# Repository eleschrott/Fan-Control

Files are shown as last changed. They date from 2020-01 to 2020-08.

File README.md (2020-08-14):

# Fan-Control
### Controls by temperature the speed of a fan driven with PWM
***
This small project is intended for cooling situations where the focus is on maximum noise reduction. To achieve this goal, the temperature is measured with a sensor (LM35DT) and processed by a microcontroller. This µController generates a pulse width modulated signal with 32kHz for a fan. The duty cycle of this PWM is directly proportional to the measured temperature.

Only a few parts are needed. The software can be realized with the Arduino IDE or ohters. I use Visual Studio with the <br>[Visual Micro Plugin](https://www.visualmicro.com/), but also Atmel Studio or others should working well. Here we use an Atmel ATtiny85, but other types with at least one analog input and a PWM capable output are also suitable.
The program is small enough to work on narrow-breasted microcontrollers. Only an internal clock frequency of 8MHz is necessary to output the PWM signal at 32kHz. This frequency is necessary, because some fans tend to produce an unpleasant whistling sound at low frequencies. The controlled temperature range is between 20 and 150 degrees Celsius.

The example shown here, refers to an ATtiny85 from Atmel. For other types or manufacturers other fuses may be set. These can be found in the respective documentations of the µController.

[Circuit diagram and board layout](/KiCAD/Fancontrol) are also included, these files are created with [KiCad](https://kicad-pcb.org/).
***
For the hardware you need the following (fits on the attached board layout):
+ Atmel ATtiny85 or similar (SOIC-8)
+ Board mounted Temperature Sensor LM35DT (TO220) 
+ Darlington transistor TIP122 (TO220)
+ Diode 1N4007 (THT)
+ Resistors: 1k, 10k (SMD 0805)
+ Capacitors: 100n, 10µ (SMD 0603)
+ Connectors: 1x 2Pin, 1x 3Pin, 1x 4Pin (THT)
+ Pinheader 02x03 Pins (THT)
+ 12V DC fan

The project requires two DC voltages, 5V for the µController and 12V for the fan. The power consumption at 12V depends on the fan type. The control needs very little current (max.12mA). In order to cope with an increased power consumption of the fan, it is recommended to provide the transistor with a heat sink. At low current consumption, the transistor can be operated without.
The circuit board is designed in such a way that the transistor is soldered in reverse, with the front side lying on the board, so that the heat sink I have in stock, can be mounted as flat as possible.

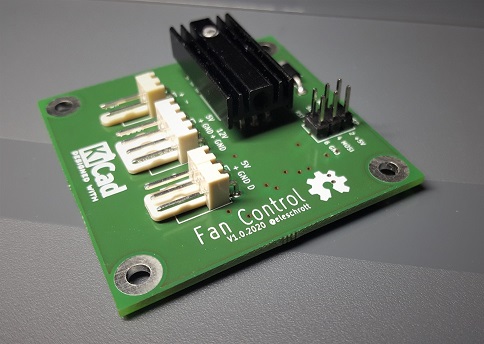
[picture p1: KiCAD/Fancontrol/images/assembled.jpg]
The parts I used for the circuit board were still available in my workshop. Of course, the used parts can vary in size and shape. It is only important that the microcontroller used, harmonizes with the software and that the peripherals can be controlled safely.
***
The circuit diagram is quite clear and does not require any great explanation. 
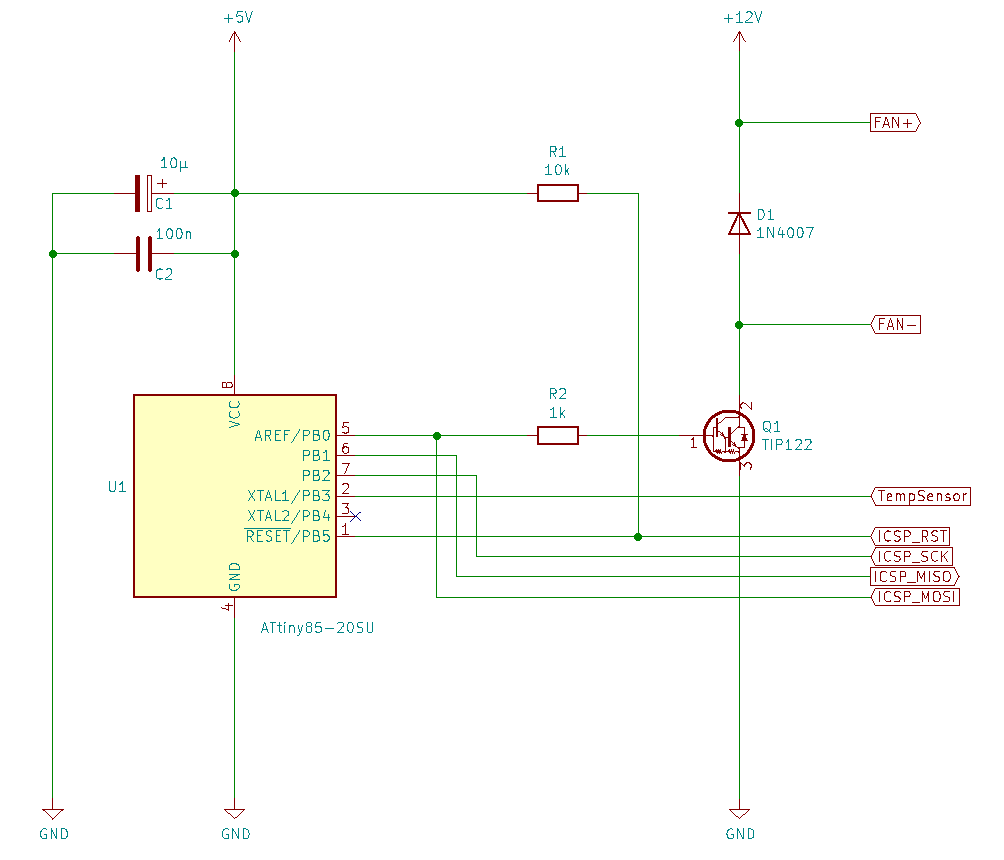
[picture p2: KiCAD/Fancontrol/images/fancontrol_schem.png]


***

In order to define the ranges for the control, the header file **Fancontrol.h** contains some constants, which can be adapted to the respective requirements.

```c
// Temperature values to define the ranges.
// We use no float variables, all temperatures gets calculated in 16Bit uint16_t!
// This means a value of 2350 corresponds to a temperature of 23.50 degrees Celsius
constexpr auto TEMP_MINHYS  = 2350; // Hysteresis for minimum temp to switch off the running fan
constexpr auto TEMP_MIN     = 2500; // Minimum Temp to switch on the fan
constexpr auto TEMP_NORMHYS = 2850; // Hysteresis for temp to switch normal range off
constexpr auto TEMP_NORM    = 3000; // Start of normal range
constexpr auto TEMP_MID     = 5000; // Temp to go to high range
constexpr auto TEMP_MAX     = 7500; // Max temperature
constexpr auto TEMP_OFFSET  =   15; // Minimum integer offset, from which a temperature control
                                    // becomes effective, default is 15 -> 0.15 degree.
```

There are also constants for the adaptation of the used fan. Not every fan runs with the same PWM values.
```c
// Fan responsible parameter to run the fan in smooth and low noise as possible
// Adjust this values to your fan model!
constexpr auto FAN_OFF      =   0; // PWM 0 -> Fan off!
constexpr auto FAN_LOWLOW   =  63; // Lowest PWM to run the fan save on minimum noise
constexpr auto FAN_LOW      =  75; // Minimum for controlled "normal" run
constexpr auto FAN_MID      = 150; // Maximum for controlled normal run and minimum for high speed run
constexpr auto FAN_HIGH     = 255; // Maximum for controlled high speed
constexpr auto FAN_OFFSET   =   2; // Minimum integer offset, from which a PWM regulation
                                   // becomes effective, default is 2 -> ~ 0.8%. 
```
***
To get this project working with the Arduino IDE, you need to install a board file to give the IDE knowledge about the ATtiny. Here you can find it: https://github.com/SpenceKonde/ATTinyCore.
To operate the µController with 8MHz some fuses must be set. For the Arduino IDE, this is described in the file [How2SetCPUFuses.txt](/Arduino/FanControl/How2SetCPUFuses.txt).

On the web site [Engbedded](http://www.engbedded.com/fusecalc) you can find a "AVR Fuse Calculator". Here you can verify the Low, High and Extended fuses.
```
avrdude: safemode: lfuse reads as E2
avrdude: safemode: hfuse reads as D7
avrdude: safemode: efuse reads as FF
```
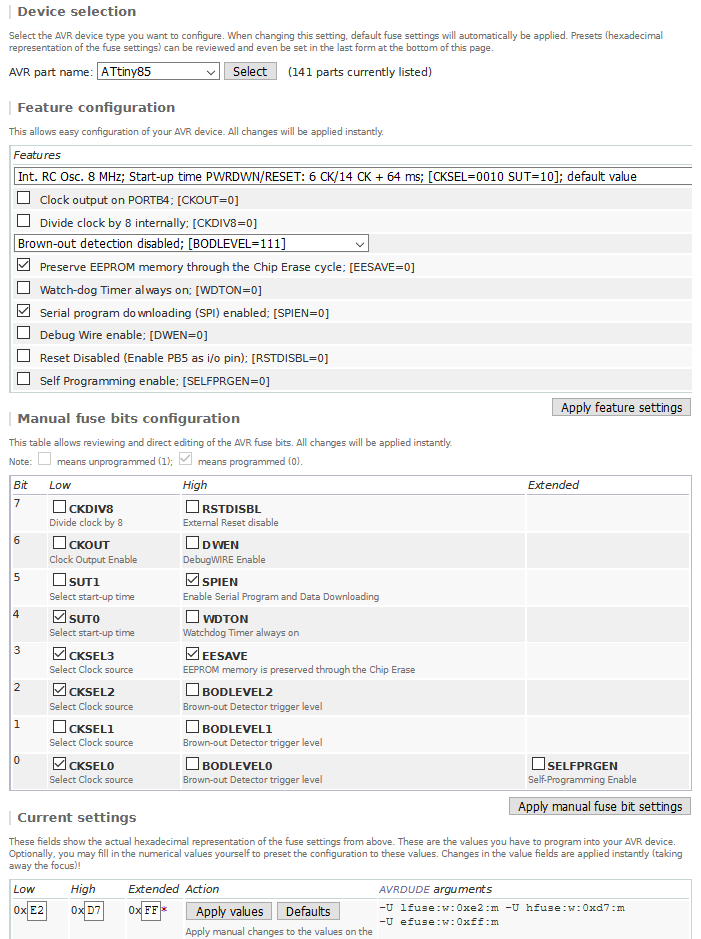
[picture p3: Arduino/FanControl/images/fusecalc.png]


***
ISP is used to program the microcontroller. It is also possible to flash the µcontroller before soldering and omit the pin headers for ISP. For adjustments to the program it is recommended to mount the 6pin header.
***

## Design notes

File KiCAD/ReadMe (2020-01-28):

Here you can find the KiCAD files, including schematic and pcb layout

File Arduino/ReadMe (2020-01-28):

Here you can find the raw Arduino version

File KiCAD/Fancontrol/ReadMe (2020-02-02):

Files for KiCad 5.1.5

It is not necessary to have a two-sided circuit board. If you want to make the circuit board yourself, one layer is perfectly sufficient.
The layout included here is single sided, the top side consists only of a groundplane.

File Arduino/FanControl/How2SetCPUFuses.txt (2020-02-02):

####################################################
# How to set the ATtiny fuses with the Arduino IDE #
####################################################

For this project you need to install a board file to give the IDE knowledge about the ATtiny.
Here you can find it: https://github.com/SpenceKonde/ATTinyCore

You can program the ATtiny by ISP. I use here an Atmel ICE in ISP mode, but also an Arduino Uno is handy to program this µController.

To set the CPU frequency to 8MHz with the Arduino IDE, you need to start to burn a bootloader.
This doesn't burn a bootloader in reality, but sets the needed fuses on the Tiny.

Set the fuses:
----------------------------------------------------
Start the Arduino IDE.

Use the following settings (e.g. for a ATtiny85):

1. Select board					: ATtiny25/45/85
2. Select chip					: ATtiny85
3. Select clock					: 8 MHz internal
4. B.O.D. level					: B.O.D. disabled
5. Save EEPROM					: EEPROM retained
6. Timer 1 clock				: CPU
7. LTO						: enabled
8. millis()/micros()    			: disabled

Execute the menu item Tools / Burn Bootloader.
----------------------------------------------------

This changes the fuses so the processor runs at 8 MHz using the internal oscillator.
It's also a handy way of "erasing" the processor when switching between projects.

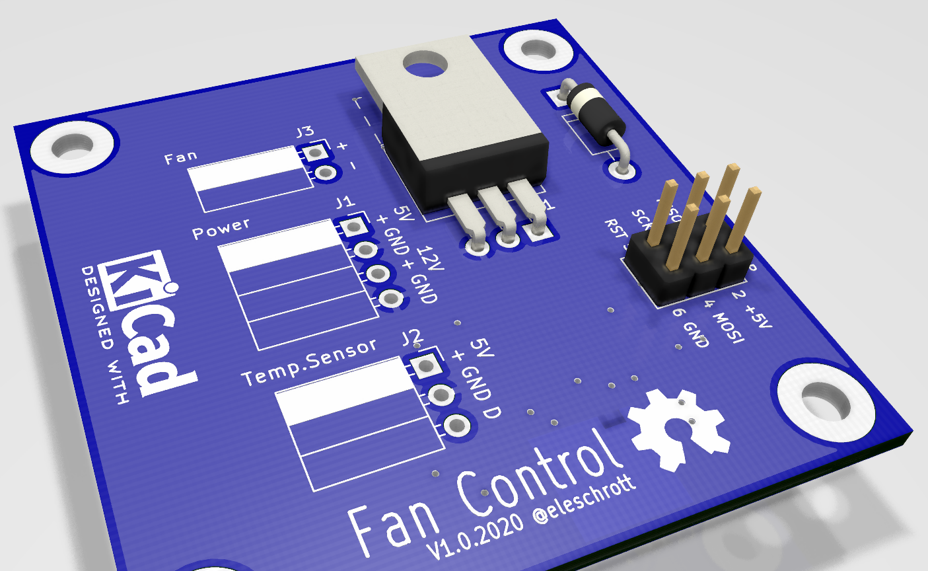
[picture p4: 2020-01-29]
KiCAD/Fancontrol/images/pcb_top.png

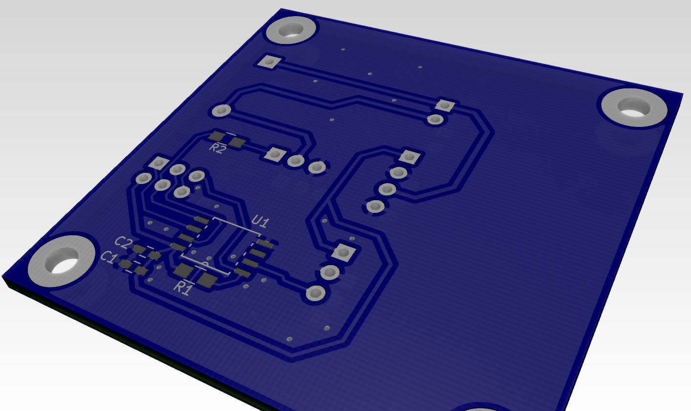
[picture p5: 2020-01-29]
KiCAD/Fancontrol/images/pcb_back_raw.png

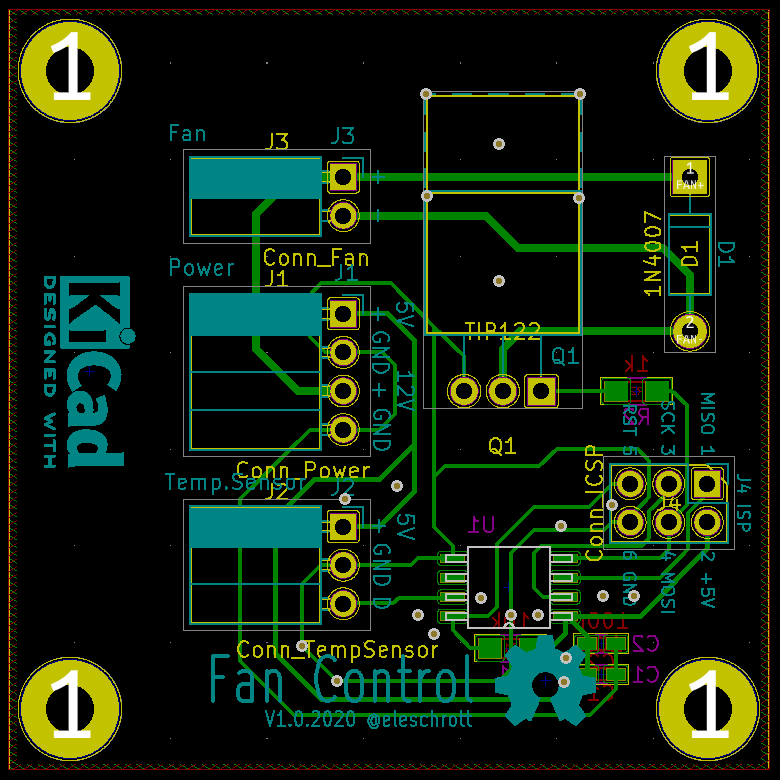
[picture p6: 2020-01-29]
KiCAD/Fancontrol/images/pcb.png

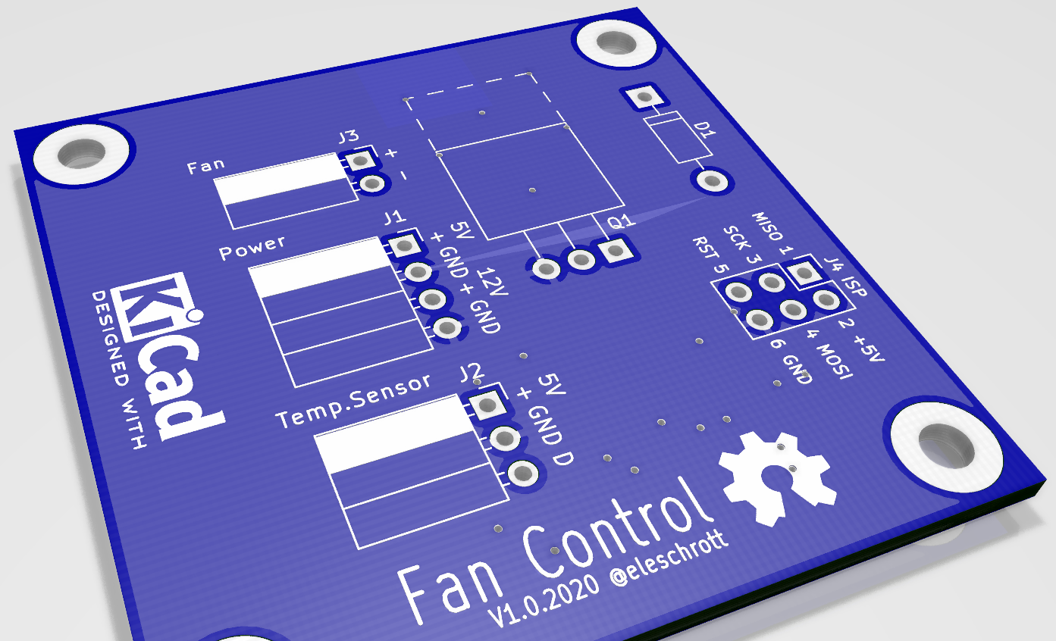
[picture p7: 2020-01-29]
KiCAD/Fancontrol/images/pcb_top_raw.png

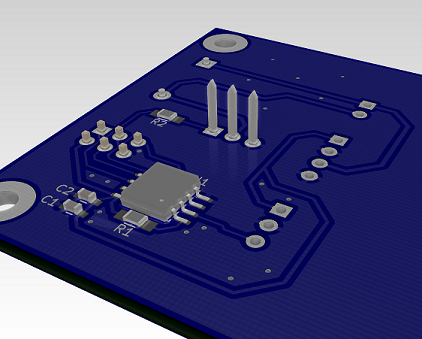
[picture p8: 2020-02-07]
KiCAD/Fancontrol/images/pcb_back.png

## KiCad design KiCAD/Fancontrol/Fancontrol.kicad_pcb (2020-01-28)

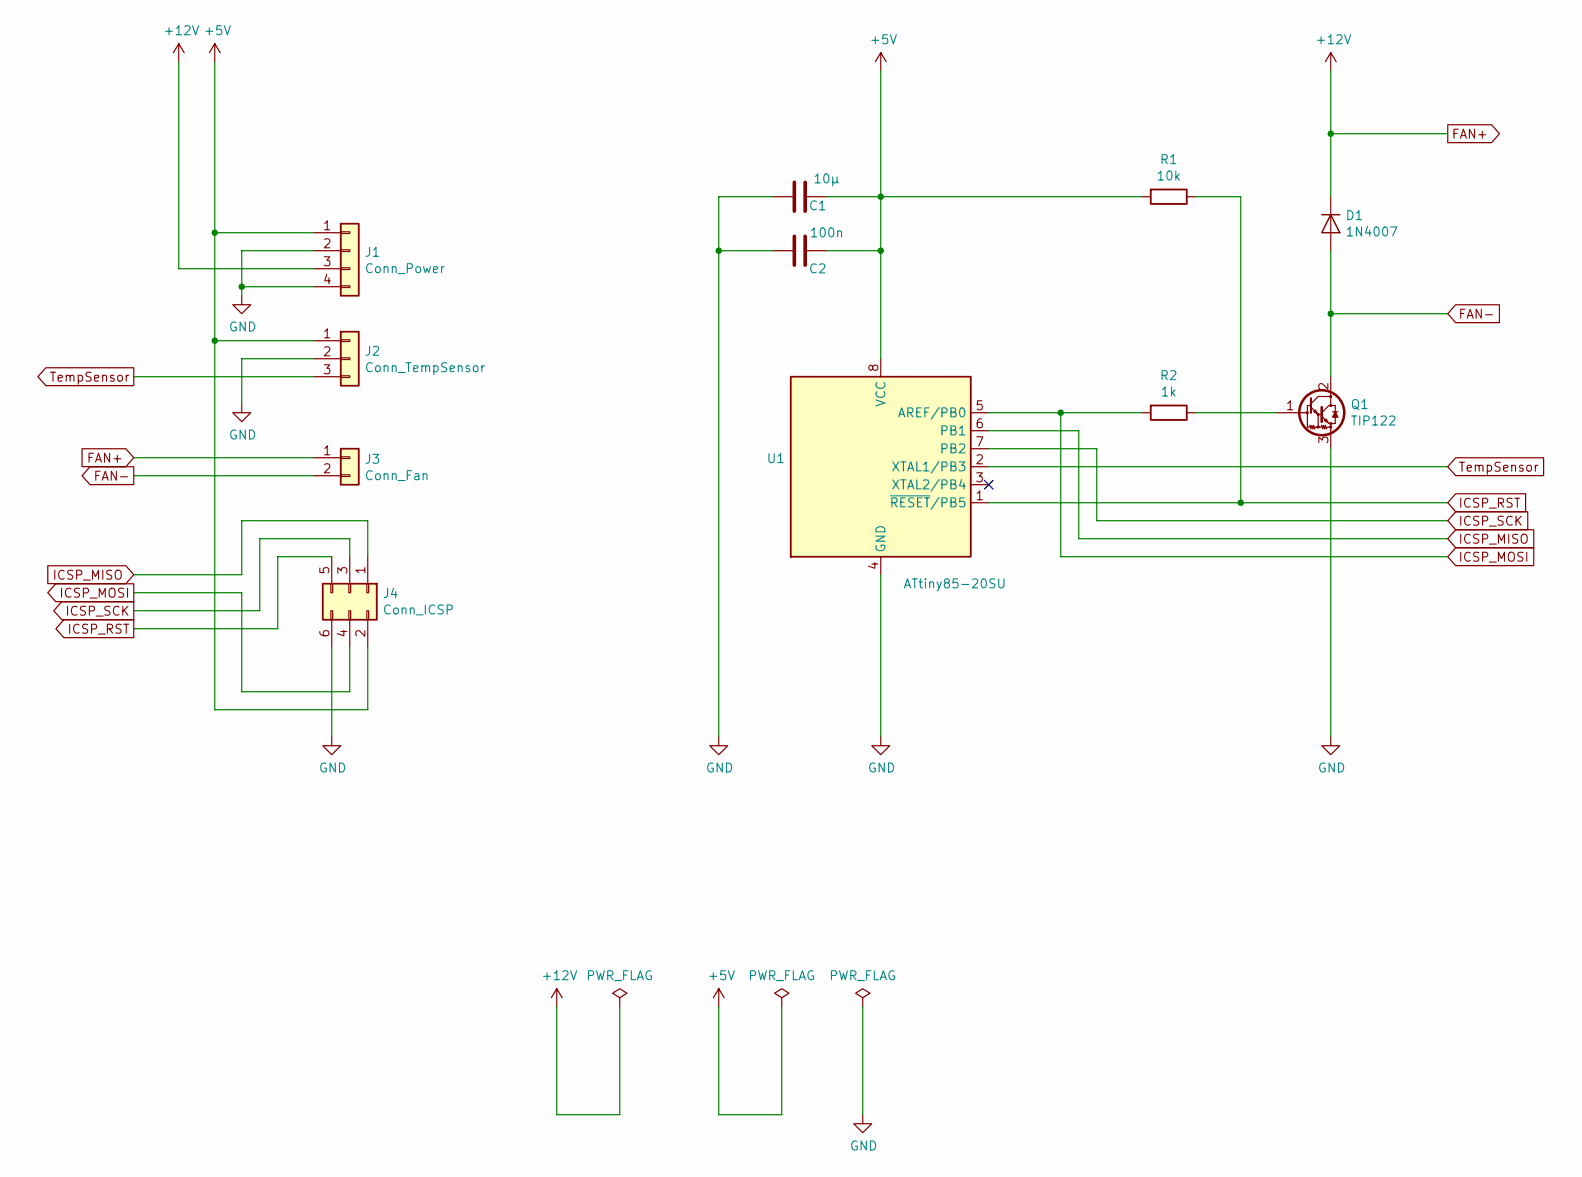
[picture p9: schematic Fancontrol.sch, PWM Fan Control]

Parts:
C1: 10µ; C_0603_HandSoldering
C2: 100n; C_0603_HandSoldering
D1: 1N4007; D_DO-41_SOD81_P10.16mm_Horizontal
J1: Conn_Power; Socket_MOLEX-KK-RM2-54mm_Lock_4pin_straight
J2: Conn_TempSensor; Socket_MOLEX-KK-RM2-54mm_Lock_3pin_straight
J3: Conn_Fan; Socket_MOLEX-KK-RM3-96mm_Lock_2pin_straight
J4: Conn_ICSP; Pin_Header_Straight_2x03_Pitch2.54mm
Q1: TIP122; TO-220-3_Vertical
R1: 10k; R_0805_HandSoldering
R2: 1k; R_0805_HandSoldering
U1: ATtiny85-20SU; SOIC127P798X216-8N

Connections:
+5V: C1.1, C2.1, J1.1, J2.1, J4.2, R1.2, U1.8 (VCC)
FAN+: D1.1 (K), J1.3, J3.1
FAN-: D1.2 (A), J3.2, Q1.2 (C)
GND: C1.2, C2.2, J1.2, J1.4, J2.2, J4.6, Q1.3 (E), U1.4 (GND)
ICSP_MISO: J4.1, U1.6 (PB1)
ICSP_MOSI: J4.4, R2.2, U1.5 (AREF/PB0)
ICSP_RST: J4.5, R1.1, U1.1 (~RESET~/PB5)
ICSP_SCK: J4.3, U1.7 (PB2)
unnamed: Q1.1 (B), R2.1
TempSensor: J2.3, U1.2 (XTAL1/PB3)

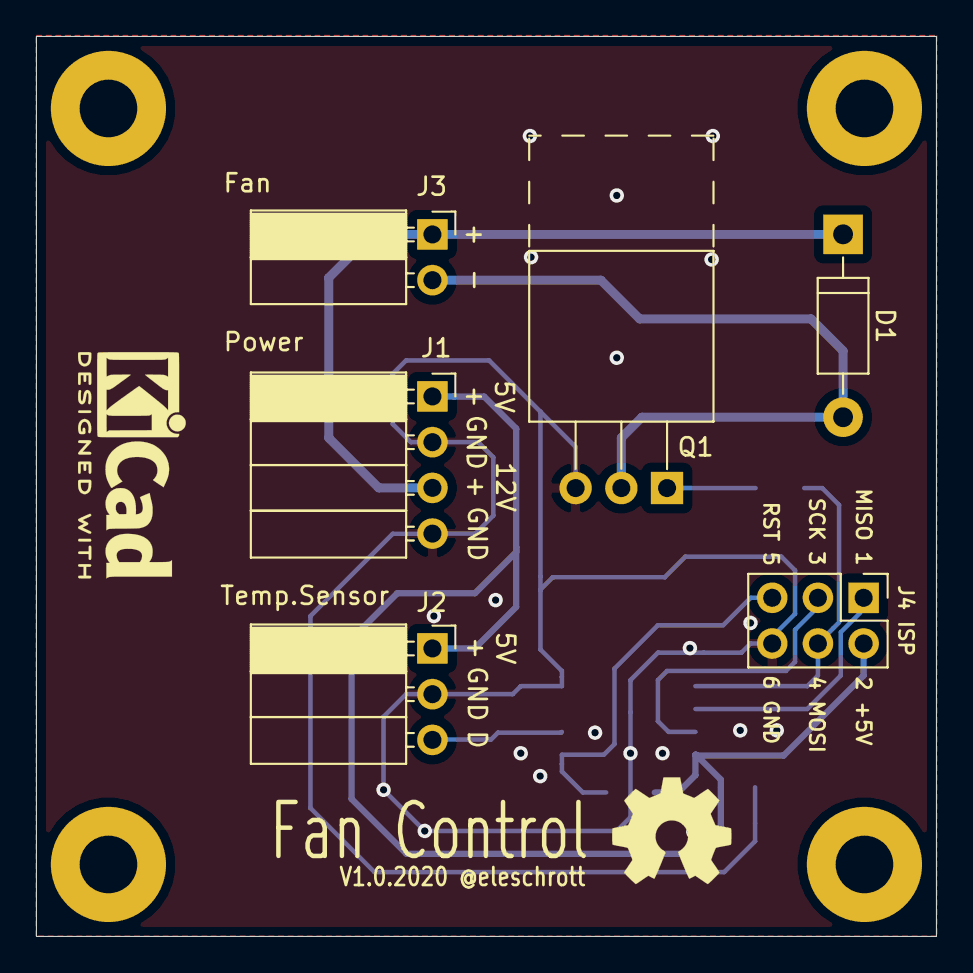
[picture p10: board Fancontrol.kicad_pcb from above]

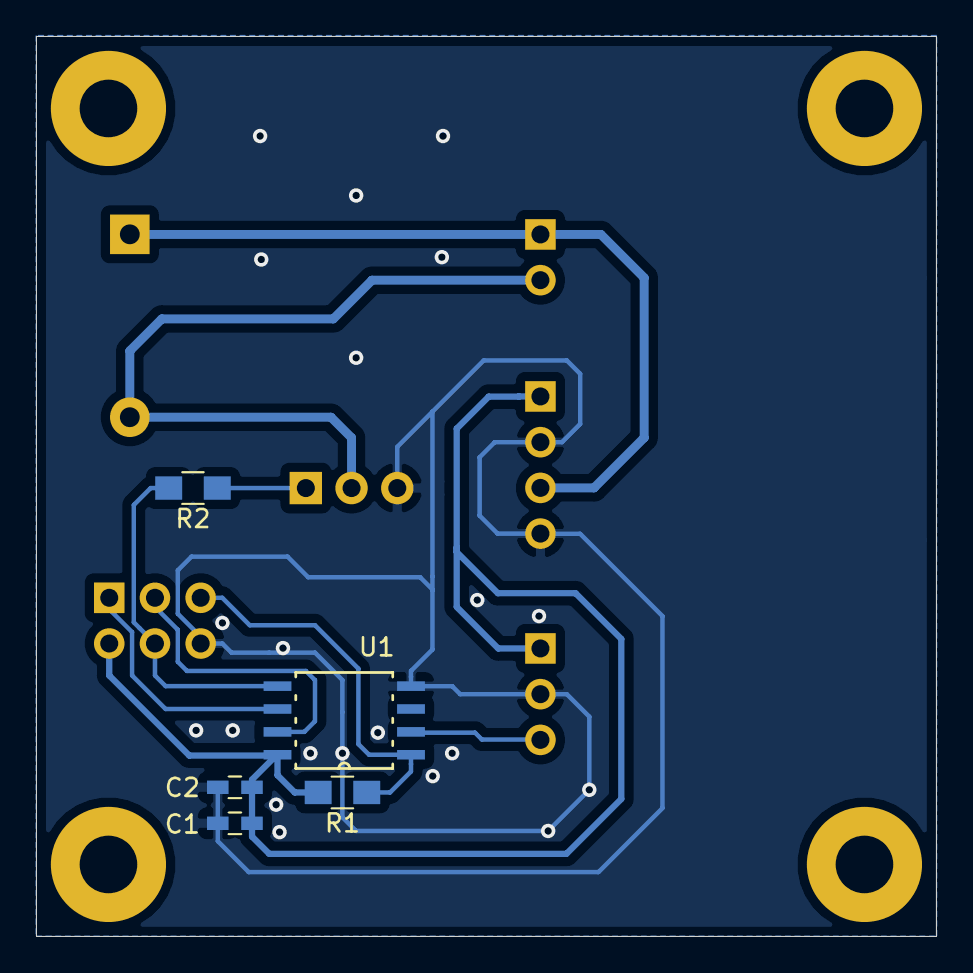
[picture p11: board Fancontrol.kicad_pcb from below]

Board: 2 copper layers, 50.0 x 50.0 mm, 11 parts (5 on the bottom side), 10 nets.

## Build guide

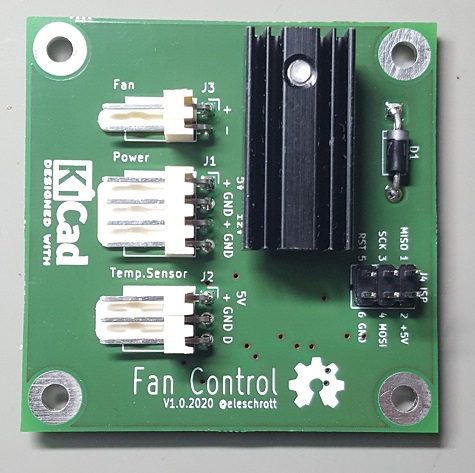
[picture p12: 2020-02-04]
KiCAD/Fancontrol/images/assembled_top.jpg

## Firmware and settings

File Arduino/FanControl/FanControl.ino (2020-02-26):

/// ***********************
/// Name       :   FanControl.ino
/// Created    :   04.Feb 2020
/// Version    :   01.01.2020
/// Author     :   eleschrott
/// 
/// Controls the speed of a fan driven by PWM with measured temperature.
/// Emphasis is placed on maximum noise reduction.
/// ***********************

#include "FanControl.h"

/// ********************************************************************************
/// <summary>
///     Reads the temperature and give them back as 16Bit value in Celsius
///     without a decimal dot.
///     e.g. 2354 for 23.54 degrees Celsius
/// </summary>
/// <returns>Temperature in Celsius</returns>
/// ********************************************************************************
uint16_t readTemp(void)
{
    uint16_t actTemp;
    static int16_t lastTemp = 0;

    // Determines the sensor value three times for more accurate results
    actTemp = (uint16_t)analogRead(TEMP_SENSOR_PIN);
    delay(100);
    actTemp = actTemp + (uint16_t)analogRead(TEMP_SENSOR_PIN);
    delay(100);
    actTemp = actTemp + (uint16_t)analogRead(TEMP_SENSOR_PIN);
    actTemp= (uint16_t)(((actTemp * (uint64_t)TEMP_CONST_C) / 3) / 10000000);
 
    if (((int16_t)(actTemp + TEMP_OFFSET) > lastTemp) || ((int16_t)(actTemp - TEMP_OFFSET) < lastTemp))
    {
        lastTemp = (int16_t)actTemp;
    }

    return lastTemp;
}

/// ********************************************************************************
/// <summary>
///     Set the Fan speed
/// </summary>
/// <param name="_speed">Speed between 0 - 255</param>
/// ********************************************************************************
void setFanSpeed(uint8_t _speed)
{
    static int16_t actualFanSpeed = FAN_OFF;

    if ((int16_t)_speed != actualFanSpeed)
    {
        if (((int16_t)_speed > (actualFanSpeed + FAN_OFFSET)) ||
           (((int16_t)_speed < (actualFanSpeed - FAN_OFFSET))) ||
             (_speed == FAN_HIGH) || (_speed == FAN_OFF))
        {
            // Workaround for Fan "spinning hole"
            #if defined FAN_SPEED_WORKAROUND && FAN_SPEED_WORKAROUND == 1 
            if ((_speed >= FAN_PROBLEM) && (_speed < FAN_FIX)) _speed = FAN_FIX;
            #endif

            analogWrite((uint8_t)FAN_PIN, (int)_speed);
            actualFanSpeed = (int16_t)_speed;
        }
    }
}

void setup()
{
    TCCR0B = TCCR0B & (0b11111000 | 0b001); // Set pre scale to one -> 32kHz PWM

    analogReference(INTERNAL);
    pinMode(FAN_PIN, OUTPUT);

    setFanSpeed((uint8_t)FAN_HIGH); // Switch fan on/off to indicate start up
    delay(3000);
    setFanSpeed((uint8_t)FAN_OFF);
}

void loop()
{
    uint16_t temperature = readTemp();

    if (temperature > (uint16_t)TEMP_MAX) // Max speed on max. temperature
    {
        setFanSpeed((uint8_t)FAN_HIGH);
    }
    else if (temperature <= (uint16_t)TEMP_MINHYS) // Fan off on low temperature
    {
        setFanSpeed((uint8_t)FAN_OFF);
    }
    else if ((temperature >= (uint16_t)TEMP_MIN) && (temperature <= (uint16_t)TEMP_NORMHYS)) // Low speed on low temperature
    {
       setFanSpeed((uint8_t)FAN_LOWLOW);
    }
    else if ((temperature > (uint16_t)TEMP_NORM) && (temperature <= (uint16_t)TEMP_MID)) // map speed between FAN_LOW and FAN_MID
    {
        setFanSpeed((uint8_t)map((long)temperature, (long)TEMP_NORM, (long)TEMP_MID, (long)FAN_LOW, (long)FAN_MID));
    }
    else if ((temperature > (uint16_t)TEMP_MID) && (temperature <= (uint16_t)TEMP_MAX)) // map speed between FAN_MID an FAN_HIGH
    {
        setFanSpeed((uint8_t)map((long)temperature, (long)TEMP_MID, (long)TEMP_MAX, (long)FAN_MID, (long)FAN_HIGH));
    }
}

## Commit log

2020-01-28 Create . Arduino
2020-01-28 Add text about sensor to schematic
    [Fancontrol.sch]
2020-01-29 Update capacitor C1
2020-01-31 add brackets to the macro SetPWM32kHz()
2020-02-02 Disable the millis()/micros() selection
    The delay()-function only works, if this is disbaled.
2020-02-04 Add offsets
    Offset for the temperature control and the PWM regulation added.
2020-02-04 Add offset calculation
    Added calculations with offsets for temperature and PWM
2020-02-04 Add offsets
    Added offsets for temperature control and pwm calculation
2020-02-04 Add offset calculations
    Added calculations with offsets for temperature control and PWM calculation
2020-02-10 Add check of "fan off"
2020-02-10 Add links to KiCad
2020-02-18 Erase obsolete fan on/off on setup()
2020-02-26 Fixed variable _speed in Workaround
    [FanControl.ino]
